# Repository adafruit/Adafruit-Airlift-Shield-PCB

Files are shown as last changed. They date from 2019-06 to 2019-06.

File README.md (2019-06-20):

# Adafruit-Airlift-Shield-PCB
PCB files for the Adafruit Airlift Shield

Format is EagleCAD schematic and board layout

For more details, check out the product page at

   * https://www.adafruit.com/product/4285

Adafruit invests time and resources providing this open source design, 
please support Adafruit and open-source hardware by purchasing 
products from Adafruit!

Designed by Adafruit Industries.  
Creative Commons Attribution, Share-Alike license, check license.txt for more information
All text above must be included in any redistribution

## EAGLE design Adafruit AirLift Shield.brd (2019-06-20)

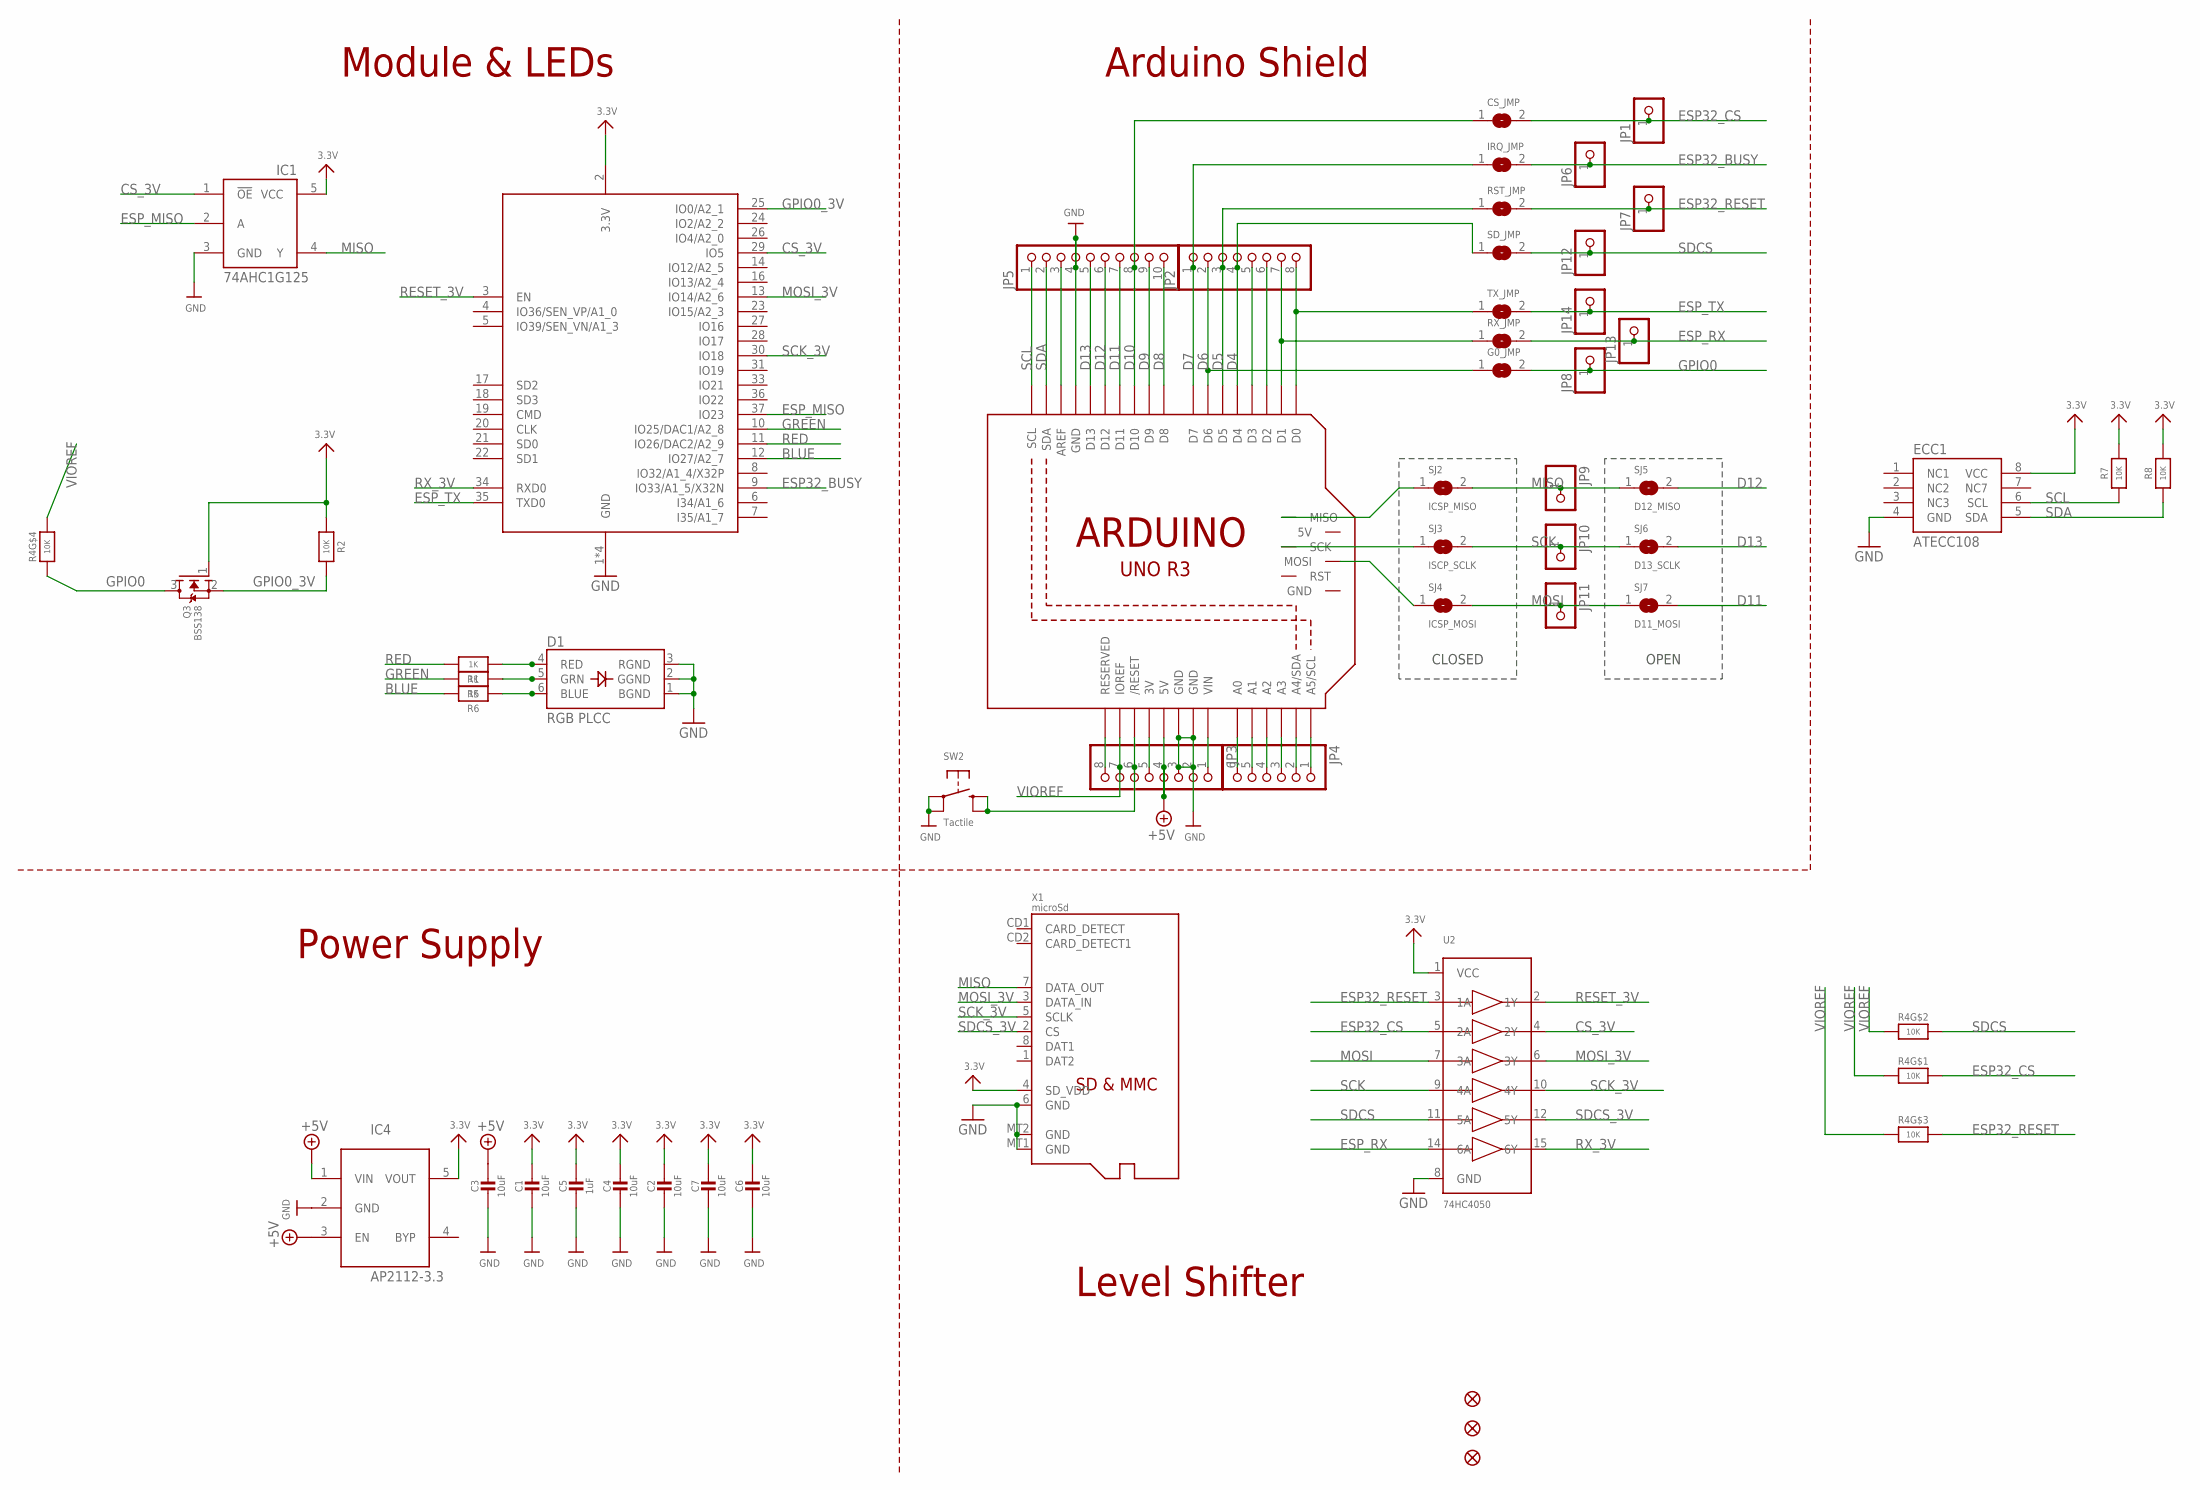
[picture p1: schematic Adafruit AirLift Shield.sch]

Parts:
C1, C2, C3, C4, C6, C7: 10uF; 0805-NO
C5: 1uF; 0805-NO
CS_JMP: SOLDERJUMPERCLOSED; SOLDERJUMPER_CLOSEDWIRE
D1: RGB PLCC; RGBLED_3535_PLCC6
ECC1: ATECC108; SOIC8
FID1, FID2, FID3: FIDUCIAL_1MM
G0_JMP: SOLDERJUMPER; SOLDERJUMPER_ARROW_NOPASTE
IC1: 74AHC1G125; SOT23-5L
IC4: AP2112-3.3; SOT23-5L
IRQ_JMP: SOLDERJUMPERCLOSED; SOLDERJUMPER_CLOSEDWIRE
JP1, JP6, JP7, JP8, JP9, JP10, JP11, JP12, JP13, JP14: HEADER-1X1ROUND; 1X01_ROUND
JP2, JP3: HEADER-1X870MIL; 1X08_ROUND_70
JP4: HEADER-1X670MIL; 1X06_ROUND_70
JP5: HEADER-1X1070MIL; 1X10_ROUND70
M1: ARDUINO_R3_ICSP_NODIM; ARDUINOR3_ICSP_NODIM
Q3: BSS138; SOT23-WIDE
R1, R5, R6: 1K; 0603-NO
R2, R7, R8: 10K; 0603-NO
R4: 10K; RESPACK_4X0603
RST_JMP: SOLDERJUMPERCLOSED; SOLDERJUMPER_CLOSEDWIRE
RX_JMP: SOLDERJUMPER; SOLDERJUMPER_ARROW_NOPASTE
SD_JMP: SOLDERJUMPERCLOSED; SOLDERJUMPER_CLOSEDWIRE
SJ2: ICSP_MISO; SOLDERJUMPER_CLOSEDWIRE
SJ3: ISCP_SCLK; SOLDERJUMPER_CLOSEDWIRE
SJ4: ICSP_MOSI; SOLDERJUMPER_CLOSEDWIRE
SJ5: D12_MISO; SOLDERJUMPER_REFLOW_NOPASTE
SJ6: D13_SCLK; SOLDERJUMPER_REFLOW_NOPASTE
SJ7: D11_MOSI; SOLDERJUMPER_REFLOW_NOPASTE
SW2: Tactile; EVQ-Q2_SMALLER
TX_JMP: SOLDERJUMPER; SOLDERJUMPER_ARROW_NOPASTE
U2: 74HC4050; SOIC16
X1: microSd; MICROSD
X2: ESP32_WROOM32; WROOM32

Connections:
3.3V: C1.1, C2.1, C4.1, C5.1, C6.1, C7.1, ECC1.8 (VCC), IC1.5 (VCC), IC4.5 (VOUT), Q3.1 (G), R2.1, R7.2, R8.2, U2.1 (VCC), X1.4 (SD_VDD), X2.2 (3.3V)
+3V: JP3.5, M1.3V
+5V: C3.1, IC4.1 (VIN), IC4.3 (EN), JP3.4, M1.5V
A0: JP4.6, M1.A0
A1: JP4.5, M1.A1
A2: JP4.4, M1.A2
A3: JP4.3, M1.A3
A4: JP4.2, M1.A4 (A4/SDA)
A5: JP4.1, M1.A5 (A5/SCL)
AREF: JP5.3, M1.AREF
BLUE: R6.2, X2.12 (IO27/A2_7)
CS_3V: IC1.1 (!OE), U2.4 (2Y), X2.29 (IO5)
D0: JP2.8, M1.D0, TX_JMP.1
D1: JP2.7, M1.D1, RX_JMP.1
D2: JP2.6, M1.D2
D3: JP2.5, M1.D3
D4: JP2.4, M1.D4, SD_JMP.1
D5: JP2.3, M1.D5, RST_JMP.1
D6: G0_JMP.1, JP2.2, M1.D6
D7: IRQ_JMP.1, JP2.1, M1.D7
D8: JP5.10, M1.D8
D9: JP5.9, M1.D9
D10: CS_JMP.1, JP5.8, M1.D10
D11: JP5.7, M1.D11, SJ7.2
D12: JP5.6, M1.D12, SJ5.2
D13: JP5.5, M1.D13, SJ6.2
ESP32_BUSY: IRQ_JMP.2, JP6.1, X2.9 (IO33/A1_5/X32N)
ESP32_CS: CS_JMP.2, JP1.1, R4.8 (2), U2.5 (2A)
ESP32_RESET: JP7.1, R4.6 (2), RST_JMP.2, U2.3 (1A)
ESP_MISO: IC1.2 (A), X2.37 (IO23)
ESP_RX: JP13.1, RX_JMP.2, U2.14 (6A)
ESP_TX: JP14.1, TX_JMP.2, X2.35 (TXD0)
GND: C1.2, C2.2, C3.2, C4.2, C5.2, C6.2, C7.2, D1.1 (BGND), D1.2 (GGND), D1.3 (RGND), ECC1.4 (GND), IC1.3 (GND), IC4.2 (GND), JP3.2, JP3.3, JP5.4, M1.GND, M1.GND@1 (GND), M1.GND@3 (GND), SW2.A, SW2.A' (P1), U2.8 (GND), X1.6 (GND), X1.MT1 (GND), X1.MT2 (GND), X2.1 (GND), X2.15 (GND), X2.38 (GND), X2.P$1 (GND)
GPIO0: G0_JMP.2, JP8.1, Q3.3 (D), R4.4 (1)
GPIO0_3V: Q3.2 (S), R2.2, X2.25 (IO0/A2_1)
GREEN: R5.2, X2.10 (IO25/DAC1/A2_8)
MISO: IC1.4 (Y), JP9.1, SJ2.2, SJ5.1, X1.7 (DATA_OUT)
MISO_ICSP: M1.MISO, SJ2.1
MOSI: JP11.1, SJ4.2, SJ7.1, U2.7 (3A)
MOSI_3V: U2.6 (3Y), X1.3 (DATA_IN), X2.13 (IO14/A2_6)
MOSI_ICSP: M1.MOSI, SJ4.1
unnamed: D1.4 (RED), R1.1
unnamed: D1.5 (GRN), R5.1
unnamed: D1.6 (BLUE), R6.1
NC: JP3.8, M1.RESERVED
RED: R1.2, X2.11 (IO26/DAC2/A2_9)
RESET: JP3.6, M1.RESET (/RESET), SW2.B (S), SW2.B' (S1)
RESET_3V: U2.2 (1Y), X2.3 (EN)
RX_3V: U2.15 (6Y), X2.34 (RXD0)
SCK: JP10.1, SJ3.2, SJ6.1, U2.9 (4A)
SCK_3V: U2.10 (4Y), X1.5 (SCLK), X2.30 (IO18)
SCK_ICSP: M1.SCK, SJ3.1
SCL: ECC1.6 (SCL), JP5.1, M1.SCL, R7.1
SDA: ECC1.5 (SDA), JP5.2, M1.SDA, R8.1
SDCS: JP12.1, R4.7 (2), SD_JMP.2, U2.11 (5A)
SDCS_3V: U2.12 (5Y), X1.2 (CS)
VIN: JP3.1, M1.VIN
VIOREF: JP3.7, M1.IOREF, R4.1, R4.2 (1), R4.3 (1), R4.5 (2)

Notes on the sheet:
CLOSED
OPEN
Module & LEDs
Level Shifter
Power Supply
Arduino Shield

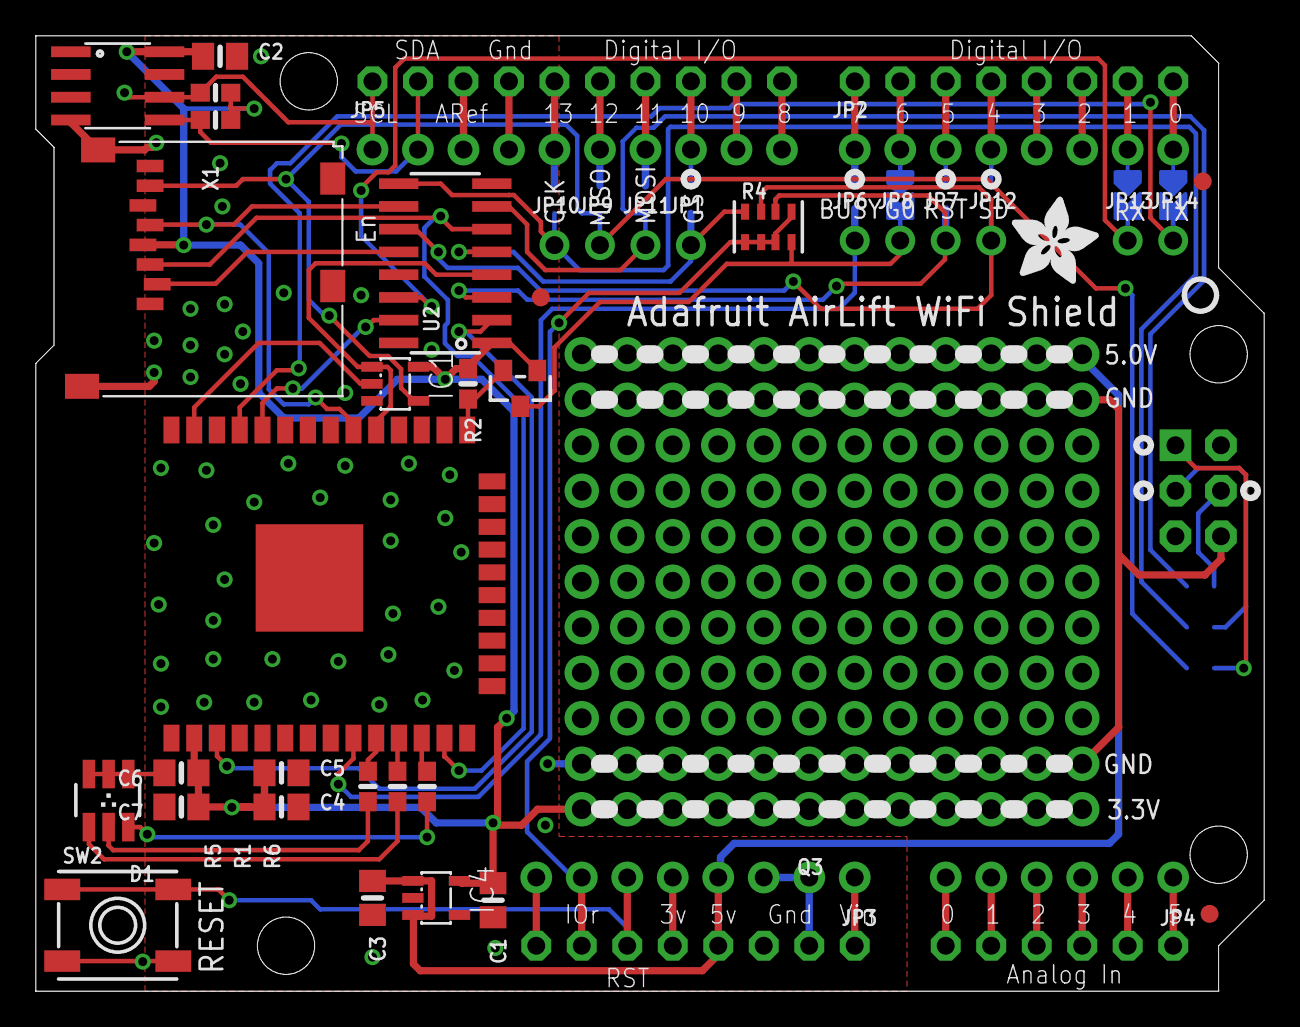
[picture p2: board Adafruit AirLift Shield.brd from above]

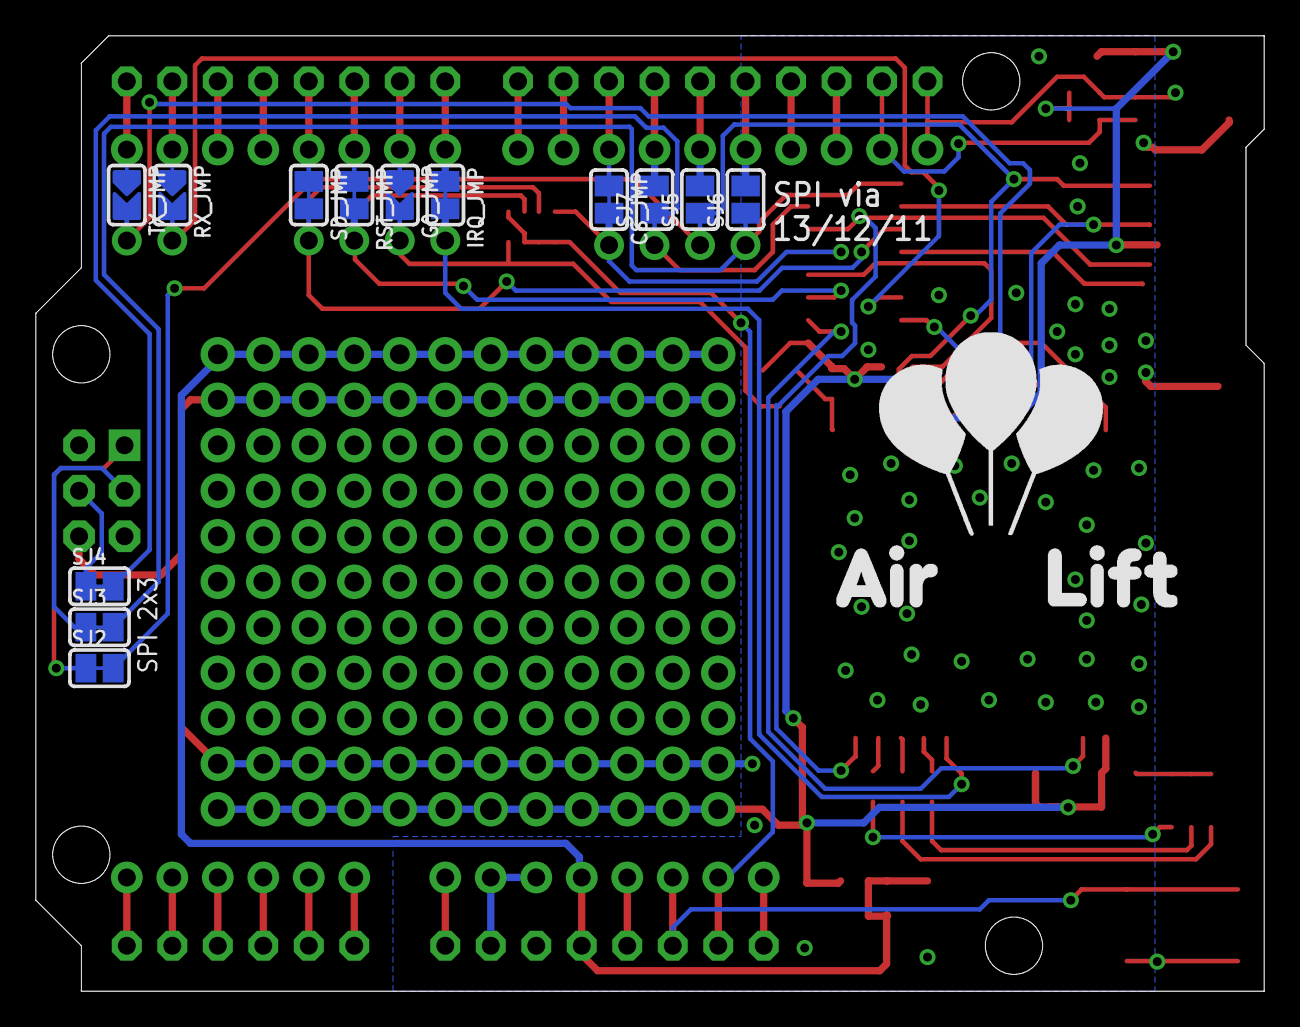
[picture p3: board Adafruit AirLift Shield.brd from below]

Board: 2 copper layers, 68.6 x 53.3 mm, 57 parts (14 on the bottom side), 58 nets.

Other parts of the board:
U$9: ADAFRUIT_5MM
U$21: PCBFEAT-REV-040
U$23: AIRLIFT

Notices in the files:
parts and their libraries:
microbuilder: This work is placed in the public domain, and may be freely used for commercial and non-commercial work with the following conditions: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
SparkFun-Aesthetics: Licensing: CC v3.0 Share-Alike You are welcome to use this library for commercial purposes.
